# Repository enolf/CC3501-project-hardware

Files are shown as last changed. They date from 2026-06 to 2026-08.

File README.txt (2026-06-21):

KiCad Local History Directory
=============================

This directory contains automatic snapshots of your project files.
KiCad periodically saves copies of your work here, allowing you to
recover from accidental changes or data loss.

You can browse and restore previous versions through KiCad's
File > Local History menu.

To disable this feature:
  Preferences > Common > Project Backup > Enable automatic backups

This directory can be safely deleted if you no longer need the
history, but doing so will permanently remove all saved snapshots.

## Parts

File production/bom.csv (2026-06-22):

Designator | Footprint | Quantity | Value | LCSC Part #
C1 | 0402 | 1 | 22pF | C1555
C10, C11, C12, C13, C14, C15, C16, C17, C18, C20, C22, C3, C35, C36, C37, C38, C39, C40, C41, C42, C9 | 0402 | 21 | 100nF | C1525
C19, C21, C6 | 0402 | 3 | 10uF | C15525
C2 | 0603 | 1 | 10uF | C19702
C23 | 0402 | 1 | 22pF C0G ±5% | C1555
C24 | 0402 | 1 | 22pF C0G ±5% | C1555
C25, C26 | 0805 | 2 | 62p NP0 2% | C520069
C27, C28 | 0603 | 2 | 56p | C107053
C29, C30, C31, C32 | 0603 | 4 | 270p NP0 2% | C327196
C33 | 0603 | 1 | 100n X7R 10% | C14663
C34 | 0603 | 1 | 1nF X7R ±10% | C1588
C4, C5 | 0402 | 2 | 33pF | C1562
C7, C8 | 0402 | 2 | 1uF | C52923
D1 | SOT-143 | 1 | PRTR5V0U2X | C316030
G1 | piicodev_logo_14.2x3.4mm | 1 | LOGO_PiicoDev
G7 | Art_2 | 1 | Label_PCB_Art
J1 | USB_C_Receptacle_G-Switch_GT-USB-7010ASV | 1 | USB_C_Receptacle_USB2.0_16P | C2988369
J4 | PinHeader_1x03_P2.54mm_Vertical | 1 | Conn_01x03_Socket
J5 | PinHeader_1x04_P2.54mm_Vertical | 1 | Conn_01x04_Socket
J6 | PinHeader_1x08_P2.54mm_Vertical | 1 | Conn_01x08_Socket
J7 | PinHeader_1x04_P2.54mm_Vertical | 1 | Conn_01x04
J8 | PinHeader_1x06_P2.54mm_Vertical | 1 | Conn_01x06_Socket
J9 | PinHeader_1x02_P2.54mm_Vertical | 1 | Conn_01x02_Socket
L1 | IND-SMD_L4.5-W4.0 | 1 | 1uH | C2929415
L2, L3 | 0805 | 2 | 1uH | C108959
L4 | 0805 | 1 | 10uH | C1046
Q1 | SOT-23 | 1 | SS8550 | C8542
Q3, Q4 | SOT-23 | 2 | AO3401A | C15127
R1, R2 | 0201 | 2 | 5K1 | C23186
R10 | 0603 | 1 | 4.7k | C23162
R11, R14, R15, R28 | 0402 | 4 | 100 | C25076
R12, R29 | 0201 | 2 | 100k | C25803
R13 | 0201 | 1 | 27R | C25190
R16 | 0805 | 1 | 20k | C4328
R17 | 0805 | 1 | 8.2k | C17828
R18, R19, R20, R21, R22, R23, R26, R27, R5 | 0805 | 9 | 10k | C17414
R24, R6, R7 | 0402 | 3 | 1k | C11702
R25 | 0603 | 1 | 820R | C23253
R3, R4 | 0603 | 2 | 27R | C25190
R8 | 0603 | 1 | 100k | C25803
R9 | 0603 | 1 | 22.1k | C31850
SW1, SW2, SW3 | SW_Push_1P1T_XKB_TS-1187A | 3 | SW_Push | C318884
U1 | QFN-56-1EP_7x7mm_P0.4mm_EP3.2x3.2mm | 1 | RP2040 | C2040
U3 | VQFN-32-1EP_5x5mm_P0.5mm_EP3.1x3.1mm_ThermalVias | 1 | MFRC522 | C54582189
U4 | SOT95P285X130-5N | 1 | SY8089A1AAC | C479074
U7 | SOIC-16_3.9x9.9mm_P1.27mm | 1 | HX711 | C6705483
U8 | SOIC-8_L5.3-W5.3-P1.27-LS8.0-BL | 1 | W25Q128JVSIQTR | C97521
Y1 | Crystal_SMD_TXC_7M-4Pin_3.2x2.5mm | 1 | X322512MSB4SI | C9002
Y2 | Crystal_SMD_3225-4Pin_3.2x2.5mm | 1 | Crystal_GND23 | C113669

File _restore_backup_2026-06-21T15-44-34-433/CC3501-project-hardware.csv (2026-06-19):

Reference | Value | Footprint | Do Not Place | Exclude from BOM | Exclude from Board | Exclude from Simulation | LCSC PN
Y1 | 27.12MHz 12pF | Crystal:Crystal_SMD_TXC_7M-4Pin_3.2x2.5mm
Y1 | X322512MSB4SI | X322512MSB4SI |  |  |  |  | C9002
U8 | W25Q128JVSIQTR | lcsc:SOIC-8_L5.3-W5.3-P1.27-LS8.0-BL |  |  |  |  | C97521
U7 | HX711 | Package_SO:SOIC-16_3.9x9.9mm_P1.27mm |  |  |  |  | C6705483
U4 | SY8089A1AAC | SOT95P285X130-5N |  |  |  |  | C479074
U2 | DS18B20 | Package_TO_SOT_THT:TO-92_Inline
U1 | RP2040 | Package_DFN_QFN:QFN-56-1EP_7x7mm_P0.4mm_EP3.2x3.2mm |  |  |  |  | C2040
U1 | MFRC522 | Package_DFN_QFN:VQFN-32-1EP_5x5mm_P0.5mm_EP3.1x3.1mm_ThermalVias
S2 | TS-1187A-B-A-B | Button_Switch_SMD:SW_Push_1P1T_XKB_TS-1187A |  |  |  |  | C318884
S1 | TS-1187A-B-A-B | Button_Switch_SMD:SW_Push_1P1T_XKB_TS-1187A |  |  |  |  | C318884
R25 | 820R | Resistor_SMD:R_0603_1608Metric
R24 | 1k | Resistor_SMD:R_0603_1608Metric
R23 | 10k | Resistor_SMD:R_0402_1005Metric
R22 | 10k | Resistor_SMD:R_0402_1005Metric
R21 | 10k | Resistor_SMD:R_0402_1005Metric
R20 | 10k
R19 | 10k
R18 | 10k
R17 | 10k
R16 | 15k
R15 | 100
R14 | 100
R13 | 100
R12 | 0603WAF1003T5E | Imported Altium Library:FP-CRCW0603-e3-IPC_B |  |  |  |  | C25803
R11 | 100 | Resistor_SMD:R_0402_1005Metric |  |  |  |  | C25076
R10 | 4.7k | Resistor_SMD:R_0603_1608Metric |  |  |  |  | C23162
R9 | 22.1k | Resistor_SMD:R_0603_1608Metric |  |  |  |  | C31850
R8 | 100k | Resistor_SMD:R_0603_1608Metric |  |  |  |  | C25803
R7 | 1K | Resistor_SMD:R_0402_1005Metric |  |  |  |  | C11702
R6 | 1k | Resistor_SMD:R_0402_1005Metric |  |  |  |  | C11702
R5 | 10k | Resistor_SMD:R_0603_1608Metric |  |  |  |  | C25804
R4 | 27R | Resistor_SMD:R_0201_0603Metric |  |  |  |  | C25190
R3 | 27R | Resistor_SMD:R_0201_0603Metric |  |  |  |  | C25190
R2 | 5K1 | Resistor_SMD:R_0201_0603Metric |  |  |  |  | C23186
R1 | 5K1 | Resistor_SMD:R_0201_0603Metric |  |  |  |  | C23186
Q2 | S8550 | Package_TO_SOT_THT:TO-92_Inline
Q1 | AO3400A | Package_TO_SOT_SMD:SOT-23 |  |  |  |  | C20917
NT11 | Net-Tie_2 | PiicoDev RFID MFRC522:NetTie-2_SMD_Pad0.80mm
NT10 | Net-Tie_2 | PiicoDev RFID MFRC522:NetTie-2_SMD_Pad0.80mm
NT9 | Net-Tie_2_Top | PiicoDev RFID MFRC522:NetTie-2_SMD_Pad0.80mm
NT8 | Net-Tie_2_Top | PiicoDev RFID MFRC522:NetTie-2_SMD_Pad0.80mm
NT4 | Net-Tie_2 | PiicoDev RFID MFRC522:NetTie-2_SMD_Pad0.80mm
L2 | 1uH | Inductor_SMD:L_0603_1608Metric
L1 | 1.0uH | SamacSys_Parts:IND-SMD_L4.5-W4.0 |  |  |  |  | C2929415
L1 | 1uH | Inductor_SMD:L_0603_1608Metric
J7 | Conn_01x06_Socket
J6 | Conn_01x08_Socket
J4 | Conn_01x04_Socket
J3 | Conn_01x03_Socket | Connector_PinHeader_2.54mm:PinHeader_1x03_P2.54mm_Vertical
J2 | Conn_01x03_Socket | Connector_PinSocket_2.54mm:PinSocket_1x03_P2.54mm_Vertical
J1 | USB_C_Receptacle_USB2.0_16P | Connector_USB:USB_C_Receptacle_G-Switch_GT-USB-7010ASV |  |  |  |  | C2988369
J1 | Conn_01x03_Socket | Connector_PinSocket_2.54mm:PinSocket_1x03_P2.54mm_Vertical
DS1 | ILI9341 | SamacSys_Parts:ILI9341
D1 | PRTR5V0U2X | Package_TO_SOT_SMD:SOT-143 |  |  |  |  | C316030
C38 | 100n | Capacitor_SMD:C_0402_1005Metric
C37 | 100n | Capacitor_SMD:C_0402_1005Metric
C36 | 100n | Capacitor_SMD:C_0402_1005Metric
C35 | 100n | Capacitor_SMD:C_0402_1005Metric
C34 | 1n NP0 10% | Capacitor_SMD:C_0603_1608Metric
C33 | 100n X7R 10% | Capacitor_SMD:C_0402_1005Metric
C32 | 270p NP0 2% | Capacitor_SMD:C_0603_1608Metric
C31 | 270p NP0 2% | Capacitor_SMD:C_0603_1608Metric
C30 | 270p NP0 2% | Capacitor_SMD:C_0603_1608Metric
C29 | 270p NP0 2% | Capacitor_SMD:C_0603_1608Metric
C28 | 56p | Capacitor_SMD:C_0603_1608Metric
C27 | 56p | Capacitor_SMD:C_0603_1608Metric
C26 | 62p NP0 2% | Capacitor_SMD:C_0603_1608Metric
C25 | 62p NP0 2% | Capacitor_SMD:C_0603_1608Metric
C24 | 22p NP0 | Capacitor_SMD:C_0402_1005Metric
C23 | 22p NP0 | Capacitor_SMD:C_0402_1005Metric
C22 | 0.1uF
C21 | 10uF
C20 | 0.1uF
C19 | 10uF
C18 | CL05B104KO5NNNC | Imported Altium Library:CAPC1050X55X23ML05T13 |  |  |  |  | C1525
C17 | CL05B104KO5NNNC | Capacitor_SMD:C_0402_1005Metric |  |  |  |  | C1525
C16 | CL05B104KO5NNNC | Capacitor_SMD:C_0402_1005Metric |  |  |  |  | C1525
C15 | CL05B104KO5NNNC | Capacitor_SMD:C_0402_1005Metric |  |  |  |  | C1525
C14 | CL05B104KO5NNNC | Capacitor_SMD:C_0402_1005Metric |  |  |  |  | C1525
C13 | CL05B104KO5NNNC | Capacitor_SMD:C_0402_1005Metric |  |  |  |  | C1525
C12 | CL05B104KO5NNNC | Capacitor_SMD:C_0402_1005Metric |  |  |  |  | C1525
C11 | CL05B104KO5NNNC | Capacitor_SMD:C_0402_1005Metric |  |  |  |  | C1525
C10 | CL05B104KO5NNNC | Capacitor_SMD:C_0402_1005Metric |  |  |  |  | C1525
C9 | CL05B104KO5NNNC | Capacitor_SMD:C_0402_1005Metric |  |  |  |  | C1525
C8 | 1uF | Capacitor_SMD:C_0402_1005Metric |  |  |  |  | C52923
C7 | 1uF | Capacitor_SMD:C_0402_1005Metric |  |  |  |  | C52923
C6 | 10uF | Capacitor_SMD:C_0402_1005Metric |  |  |  |  | C15525
C5 | 33pF | Capacitor_SMD:C_0402_1005Metric |  |  |  |  | C1562
C4 | 33pF | Capacitor_SMD:C_0402_1005Metric |  |  |  |  | C1562
C3 | 100nF | Capacitor_SMD:C_0402_1005Metric |  |  |  |  | C1525
C2 | 10uF | Capacitor_SMD:C_0603_1608Metric |  |  |  |  | C19702
C1 | 22pF | Capacitor_SMD:C_0402_1005Metric |  |  |  |  | C1555

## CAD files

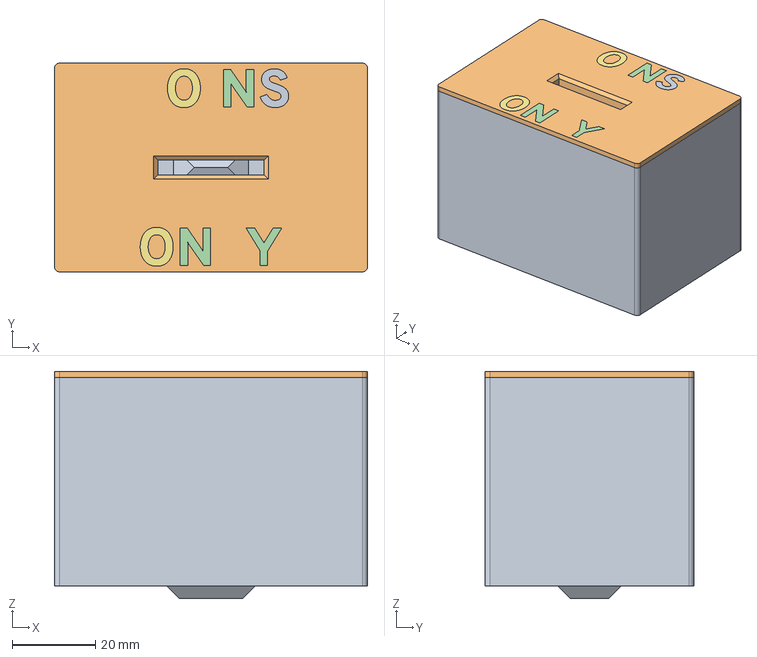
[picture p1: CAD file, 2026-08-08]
3D Printed Enclosure/Money Box.step
75.0 x 50.0 x 54.5 mm

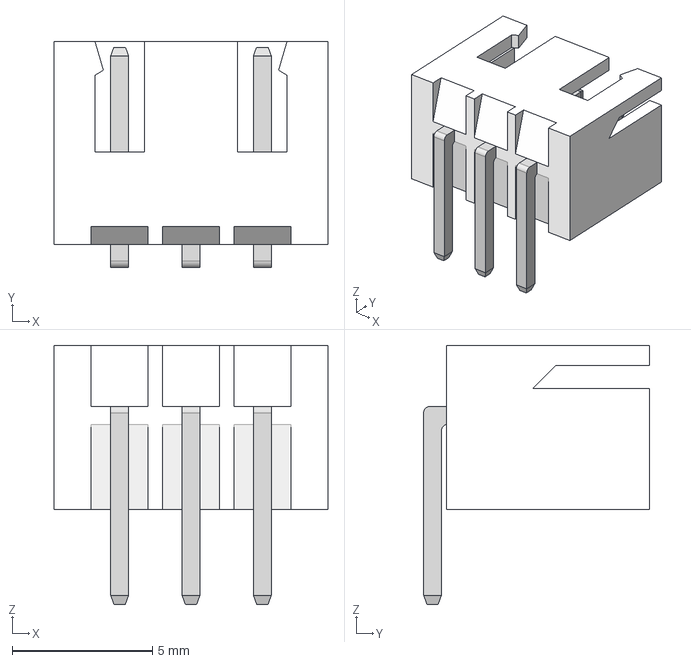
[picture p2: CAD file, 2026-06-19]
_restore_backup_2026-06-21T14-04-23-622/DS18B20_breakout_board/DS18B20-Breakout-Board/3D Files/JST - XH - Thru (R) - 3Pin - 2.54mm.stp
9.75 x 8.04 x 9.22 mm

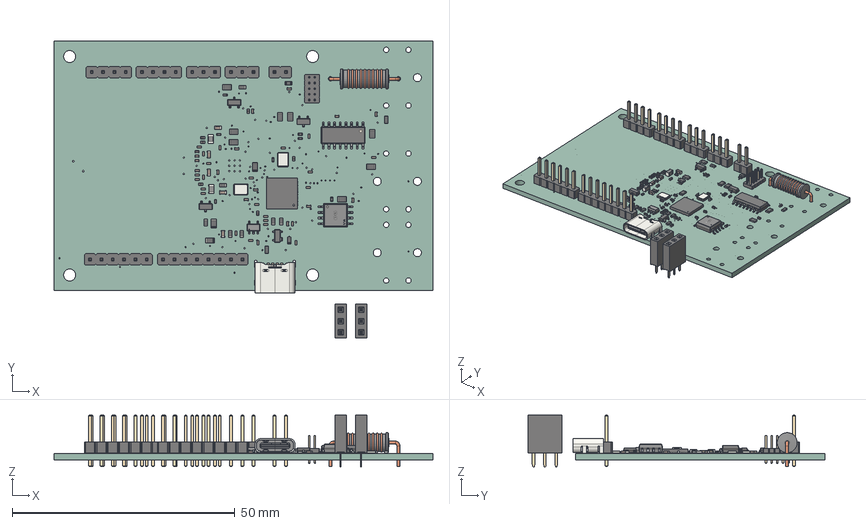
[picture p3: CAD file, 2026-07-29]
PCB.step
85.0 x 66.6 x 11.6 mm
C_0402_1005Metric x 45
R_0603_1608Metric x 11
SOT-23 x 3
R_0402_1005Metric x 7
R_0805_2012Metric x 11
Crystal_SMD_3225-4Pin_3.2x2.5mm
C_0603_1608Metric x 5
PinSocket_1x03_P2.54mm_Vertical x 2
QFN-56-1EP_7x7mm_P0.4mm_EP3.2x3.2mm
SOIC-16_3.9x9.9mm_P1.27mm
L_0805_2012Metric x 2
SOT-143
PinHeader_1x03_P2.54mm_Vertical x 2
PinHeader_1x06_P2.54mm_Vertical
PinHeader_2x05_P1.27mm_Vertical
PinHeader_1x04_P2.54mm_Vertical x 2
PinHeader_1x02_P2.54mm_Vertical
PinsArrayL
PinsArrayR
L_Axial_L11.0mm_D4.5mm_P15.24mm_Horizontal_Fastron_MECC
PinHeader_1x08_P2.54mm_Vertical
Crystal_SMD_TXC_7M-4Pin_3.2x2.5mm
USB_C_Receptacle_GCT_USB4125-xx-x_6P_TopMnt_Horizontal
SOIC-8_L5.3-W5.3-H1.9-LS7.9-P1.27
CC3501-project-hardware_PCB

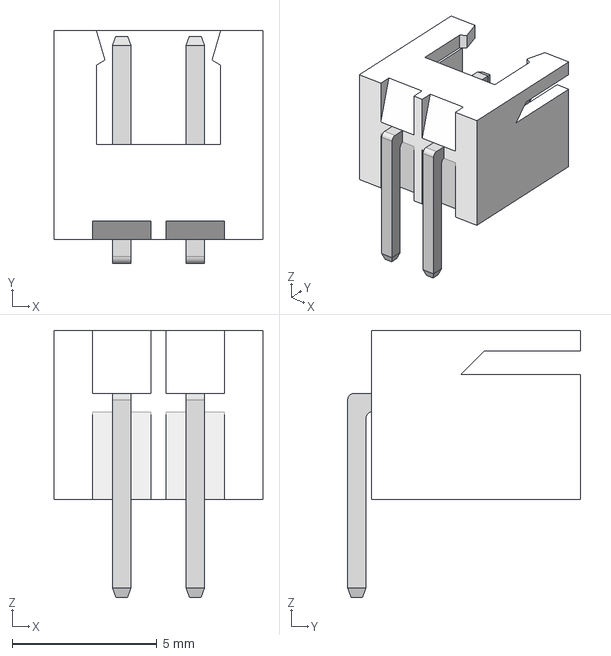
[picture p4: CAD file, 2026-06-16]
_restore_backup_2026-06-21T14-04-23-622/DS18B20_breakout_board/DS18B20-Breakout-Board/3D Files/JST - XH - Thru (R) - 2Pin - 2.54mm.stp
7.21 x 8.04 x 9.22 mm

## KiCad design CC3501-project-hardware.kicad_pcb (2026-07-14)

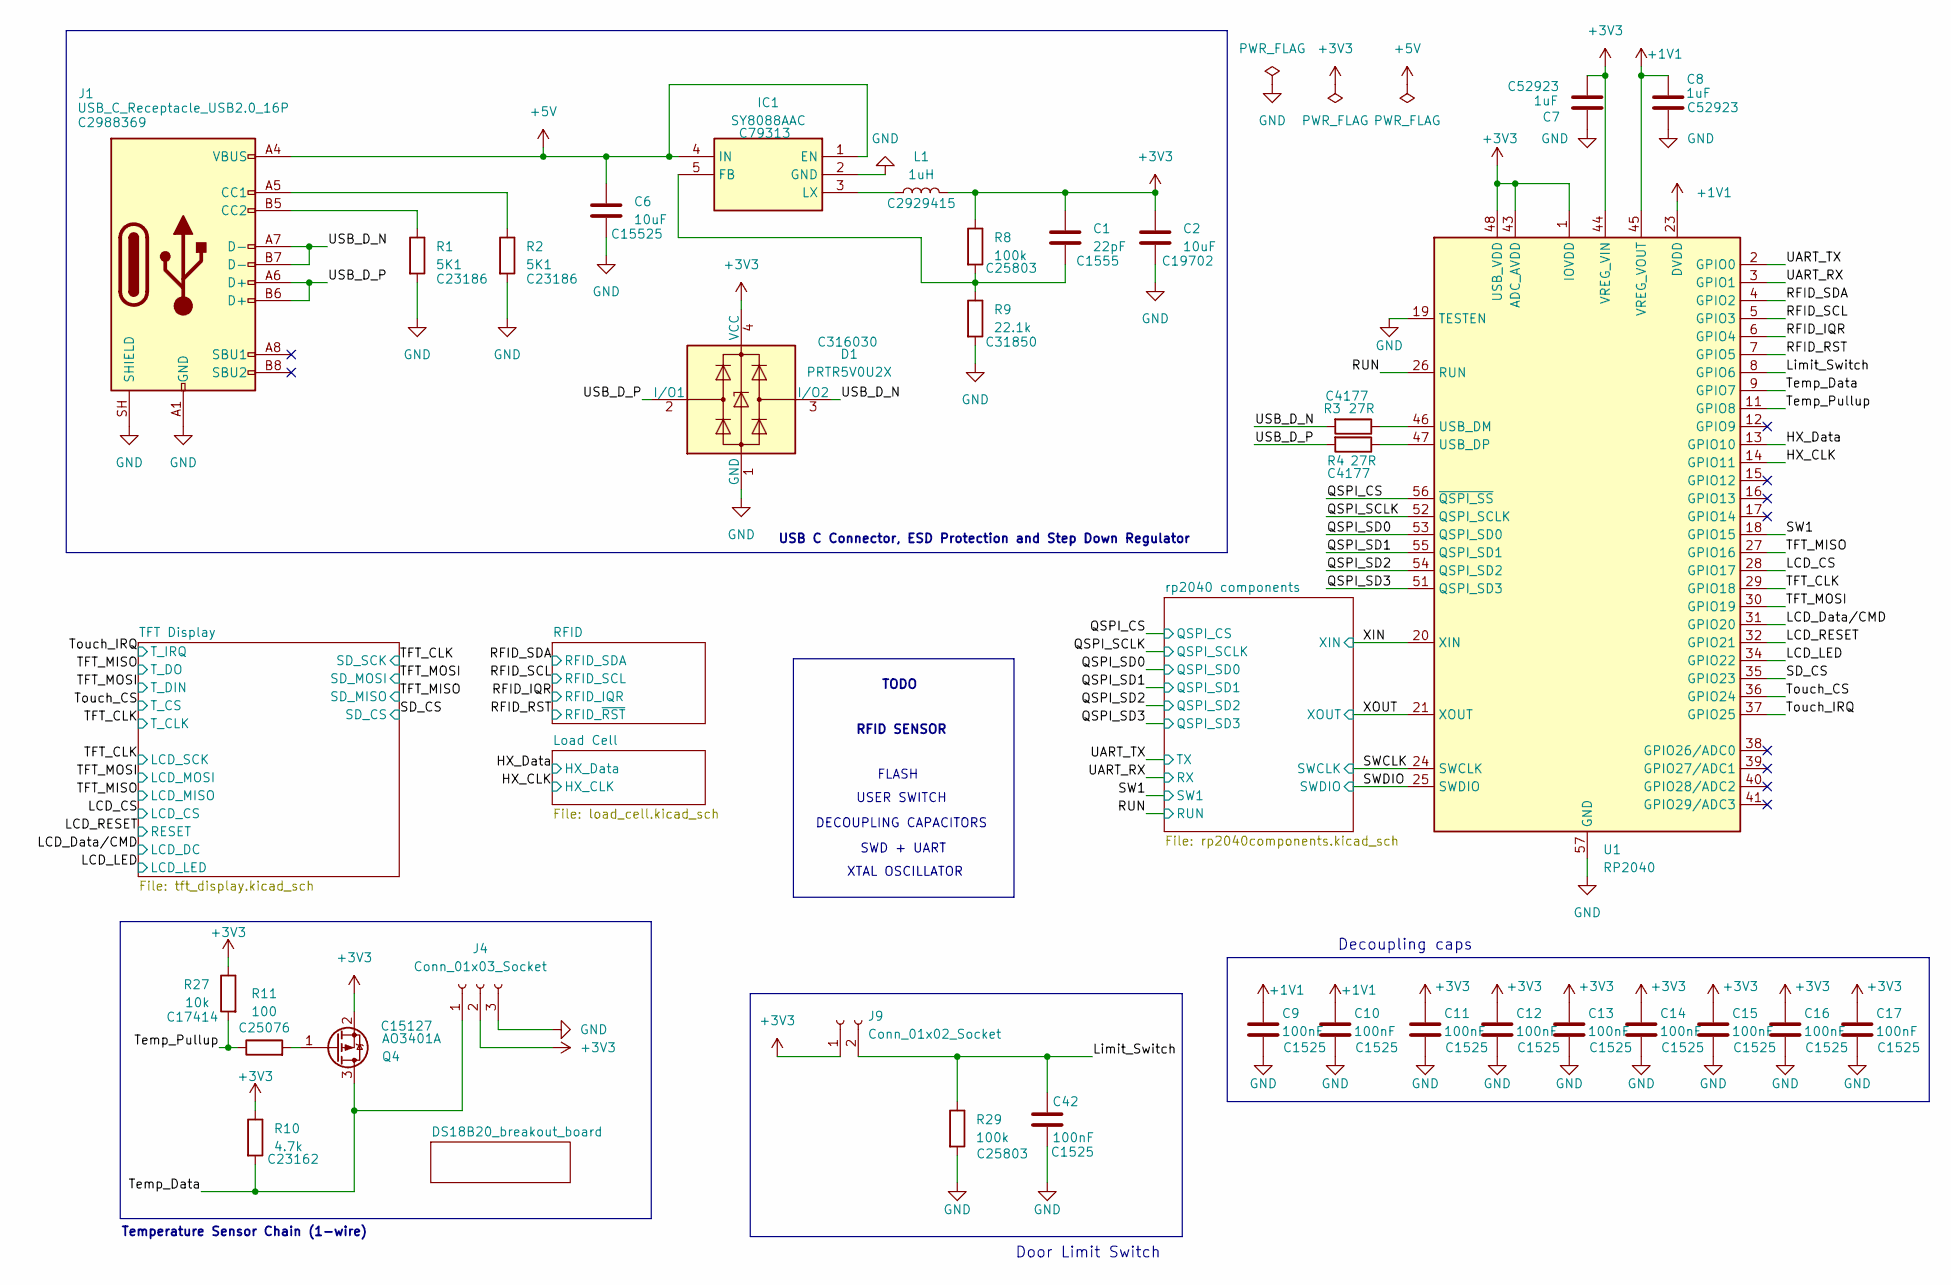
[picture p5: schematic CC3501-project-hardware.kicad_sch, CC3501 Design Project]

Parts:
C1: 22pF; C_0402_1005Metric; LCSC PN C1555
C2: 10uF; C_0603_1608Metric; LCSC PN C19702
C6: 10uF; C_0402_1005Metric; LCSC PN C15525
C7, C8: 1uF; C_0402_1005Metric; LCSC PN C52923
C9, C10, C11, C12, C13, C14, C15, C16, C17, C42: 100nF; C_0402_1005Metric; LCSC PN C1525
D1: PRTR5V0U2X; SOT-143; LCSC PN C316030
IC1: SY8088AAC; SOT95P285X140-5N; Manufacturer_Part_Number SY8088AAC
J1: USB_C_Receptacle_USB2.0_16P; USB_C_Receptacle_G-Switch_GT-USB-7010ASV; LCSC PN C2988369
J4: Conn_01x03_Socket; PinHeader_1x03_P2.54mm_Vertical
J9: Conn_01x02_Socket; PinHeader_1x02_P2.54mm_Vertical
L1: 1uH; IND-SMD_L4.5-W4.0; LCSC PN C2929415
Q4: AO3401A; SOT-23; LCSC PN C15127
R1, R2: 5K1; R_0603_1608Metric; LCSC PN C23186
R3, R4: 27R; R_0603_1608Metric; LCSC PN C4177
R8, R29: 100k; R_0603_1608Metric; LCSC PN C25803
R9: 22.1k; R_0603_1608Metric; LCSC PN C31850
R10: 4.7k; R_0603_1608Metric; LCSC PN C23162
R11: 100; R_0402_1005Metric; LCSC PN C25076
R27: 10k; R_0805_2012Metric; LCSC PN C17414
U1: RP2040; QFN-56-1EP_7x7mm_P0.4mm_EP3.2x3.2mm; LCSC PN C2040

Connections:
+1V1: C8.2, C9.1, C10.1, U1.23 (DVDD), U1.45 (VREG_VOUT), U1.50 (DVDD)
+5V: C6.1, IC1.1 (EN), IC1.4 (IN), J1.A4 (VBUS), J1.A9 (VBUS), J1.B4 (VBUS), J1.B9 (VBUS); also elsewhere on the board
/HX_CLK: U1.14 (GPIO11); also elsewhere on the board
/HX_Data: U1.13 (GPIO10); also elsewhere on the board
/LCD_CS: U1.28 (GPIO17); also elsewhere on the board
/LCD_Data/CMD: U1.31 (GPIO20); also elsewhere on the board
/LCD_LED: U1.34 (GPIO22); also elsewhere on the board
/LCD_RESET: U1.32 (GPIO21); also elsewhere on the board
/Limit_Switch: C42.1, J9.2, R29.1, U1.8 (GPIO6)
/QSPI_CS: U1.56 (~QSPI_SS); also elsewhere on the board
/QSPI_SCLK: U1.52 (QSPI_SCLK); also elsewhere on the board
/QSPI_SD0: U1.53 (QSPI_SD0); also elsewhere on the board
/QSPI_SD1: U1.55 (QSPI_SD1); also elsewhere on the board
/QSPI_SD2: U1.54 (QSPI_SD2); also elsewhere on the board
/QSPI_SD3: U1.51 (QSPI_SD3); also elsewhere on the board
/RFID_IQR: U1.6 (GPIO4); also elsewhere on the board
/RFID_RST: U1.7 (GPIO5); also elsewhere on the board
/RFID_SCL: U1.5 (GPIO3); also elsewhere on the board
/RFID_SDA: U1.4 (GPIO2); also elsewhere on the board
/RUN: U1.26 (RUN); also elsewhere on the board
/SD_CS: U1.35 (GPIO23); also elsewhere on the board
/SW1: U1.18 (GPIO15); also elsewhere on the board
/SWCLK: U1.24 (SWCLK); also elsewhere on the board
/SWDIO: U1.25 (SWDIO); also elsewhere on the board
/TFT_CLK: U1.29 (GPIO18); also elsewhere on the board
/TFT_MISO: U1.27 (GPIO16); also elsewhere on the board
/TFT_MOSI: U1.30 (GPIO19); also elsewhere on the board
/Temp_Data: J4.1, Q4.3 (D), R10.2, U1.9 (GPIO7)
/Temp_Pullup: R11.1, R27.2, U1.11 (GPIO8)
/Touch_CS: U1.36 (GPIO24); also elsewhere on the board
/Touch_IRQ: U1.37 (GPIO25); also elsewhere on the board
/USB_D_N: D1.3 (I/O2), J1.A7 (D-), J1.B7 (D-), R3.2
/USB_D_P: D1.2 (I/O1), J1.A6 (D+), J1.B6 (D+), R4.2
/XIN: U1.20 (XIN); also elsewhere on the board
/XOUT: U1.21 (XOUT); also elsewhere on the board
GND: C2.2, C6.2, C7.1, C8.1, C9.2, C10.2, C11.2, C12.2, C13.2, C14.2, C15.2, C16.2, C17.2, C42.2, D1.1 (GND), IC1.2 (GND), J1.A1 (GND), J1.A12 (GND), J1.B1 (GND), J1.B12 (GND), J1.SH (SHIELD), J4.3, R1.2, R2.2, R9.2, R29.2, U1.19 (TESTEN), U1.57 (GND); also elsewhere on the board
unnamed: C1.2, IC1.5 (FB), R8.2, R9.1
unnamed: IC1.3 (LX), L1.2
unnamed: J1.A5 (CC1), R2.1
unnamed: J1.B5 (CC2), R1.1
unnamed: Q4.1 (G), R11.2
unnamed: R3.1, U1.46 (USB_DM)
unnamed: R4.1, U1.47 (USB_DP)

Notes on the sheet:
TODO
FLASH
DECOUPLING CAPACITORS
Door Limit Switch
Decoupling caps
RFID SENSOR
SWD + UART
XTAL OSCILLATOR
USB C Connector, ESD Protection and Step Down Regulator
USER SWITCH
Temperature Sensor Chain (1-wire)

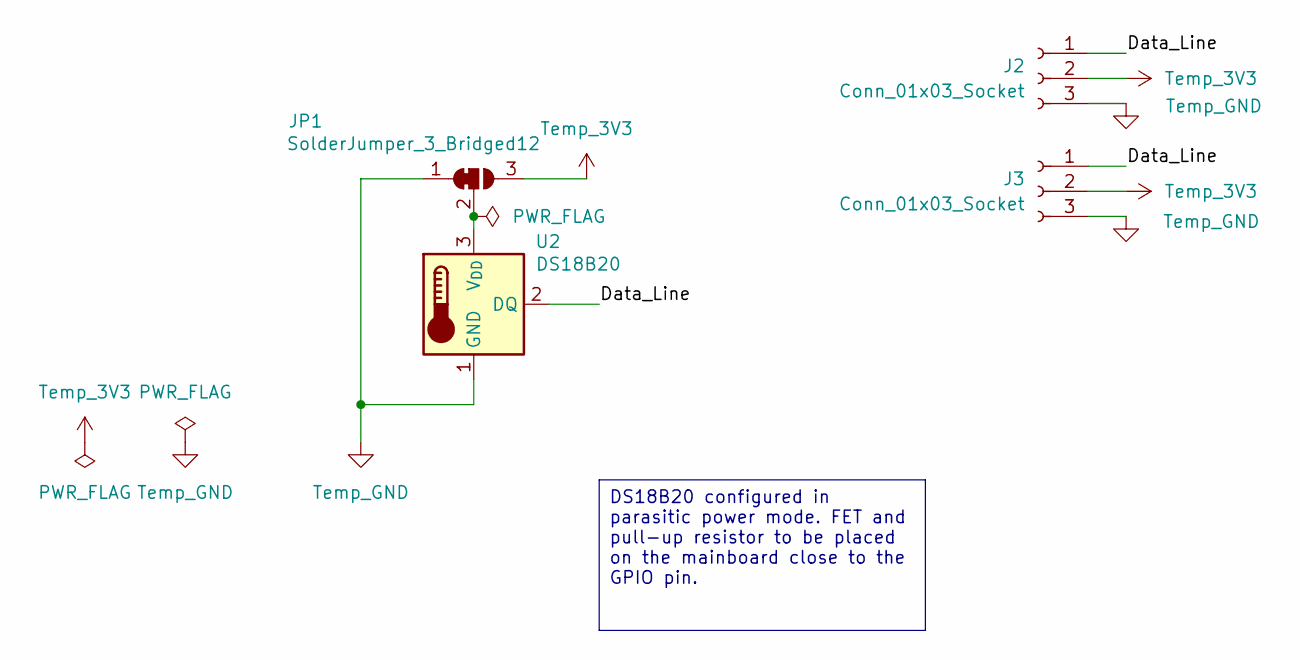
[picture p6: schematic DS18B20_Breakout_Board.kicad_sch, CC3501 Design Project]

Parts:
J2, J3: Conn_01x03_Socket; PinSocket_1x03_P2.54mm_Vertical
JP1: SolderJumper_3_Bridged12; SolderJumper-3_P1.3mm_Bridged12_RoundedPad1.0x1.5mm_NumberL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
U2: DS18B20; TO-92_Inline

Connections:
Temp_3V3: J2.2, J3.2, JP1.3 (B)

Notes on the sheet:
DS18B20 configured in parasitic power mode. FET and pull-up resistor to be placed on the mainboard close to the GPIO pin.

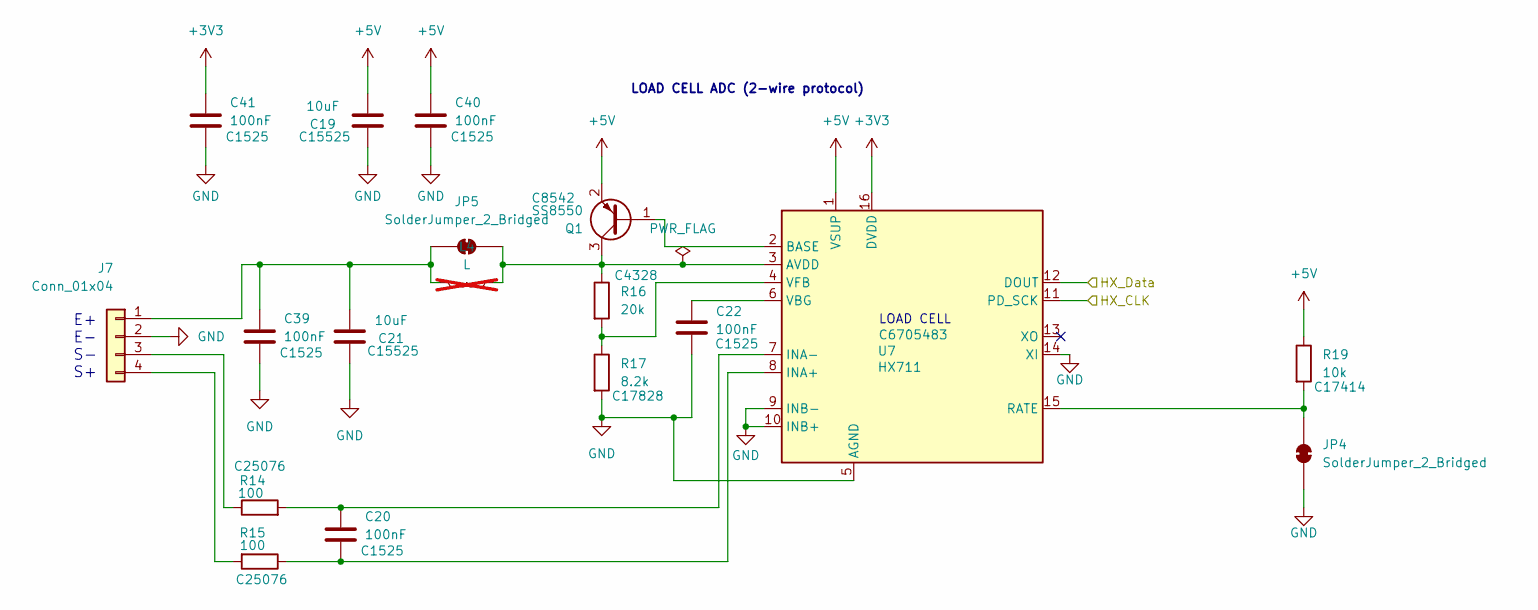
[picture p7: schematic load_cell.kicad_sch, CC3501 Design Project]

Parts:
C19, C21: 10uF; C_0402_1005Metric; LCSC PN C15525
C20, C22, C39, C40, C41: 100nF; C_0402_1005Metric; LCSC PN C1525
J7: Conn_01x04; PinHeader_1x04_P2.54mm_Vertical
JP4, JP5: SolderJumper_2_Bridged; SolderJumper-2_P1.3mm_Bridged2Bar_RoundedPad1.0x1.5mm
L4: L; L_Axial_L11.0mm_D4.5mm_P15.24mm_Horizontal_Fastron_MECC; not fitted
Q1: SS8550; SOT-23; LCSC PN C8542
R14, R15: 100; R_0402_1005Metric; LCSC PN C25076
R16: 20k; R_0805_2012Metric; LCSC PN C4328
R17: 8.2k; R_0805_2012Metric; LCSC PN C17828
R19: 10k; R_0805_2012Metric; LCSC PN C17414
U7: HX711; SOIC-16_3.9x9.9mm_P1.27mm; LCSC PN C6705483

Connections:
+5V: C19.2, C40.1, Q1.2 (E), R19.1, U7.1 (VSUP); also elsewhere on the board
/HX_CLK: U7.11 (PD_SCK); also elsewhere on the board
/HX_Data: U7.12 (DOUT); also elsewhere on the board
GND: C19.1, C21.1, C22.2, C39.2, C40.2, C41.2, J7.2, JP4.1 (A), R17.2, U7.5 (AGND), U7.9 (INB-), U7.10 (INB+), U7.14 (XI); also elsewhere on the board
unnamed: C21.2, C39.1, J7.1, JP5.2 (B), L4.1
unnamed: J7.3, R14.1
unnamed: J7.4, R15.2
unnamed: JP4.2 (B), R19.2, U7.15 (RATE)
unnamed: JP5.1 (A), L4.2, Q1.3 (C), R16.1, U7.3 (AVDD)
unnamed: Q1.1 (B), U7.2 (BASE)
unnamed: C20.2, R15.1, U7.8 (INA+)
unnamed: C20.1, R14.2, U7.7 (INA-)
unnamed: C22.1, U7.6 (VBG)
unnamed: R16.2, R17.1, U7.4 (VFB)

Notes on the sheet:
E+ E- S- S+
LOAD CELL ADC (2-wire protocol)
LOAD CELL

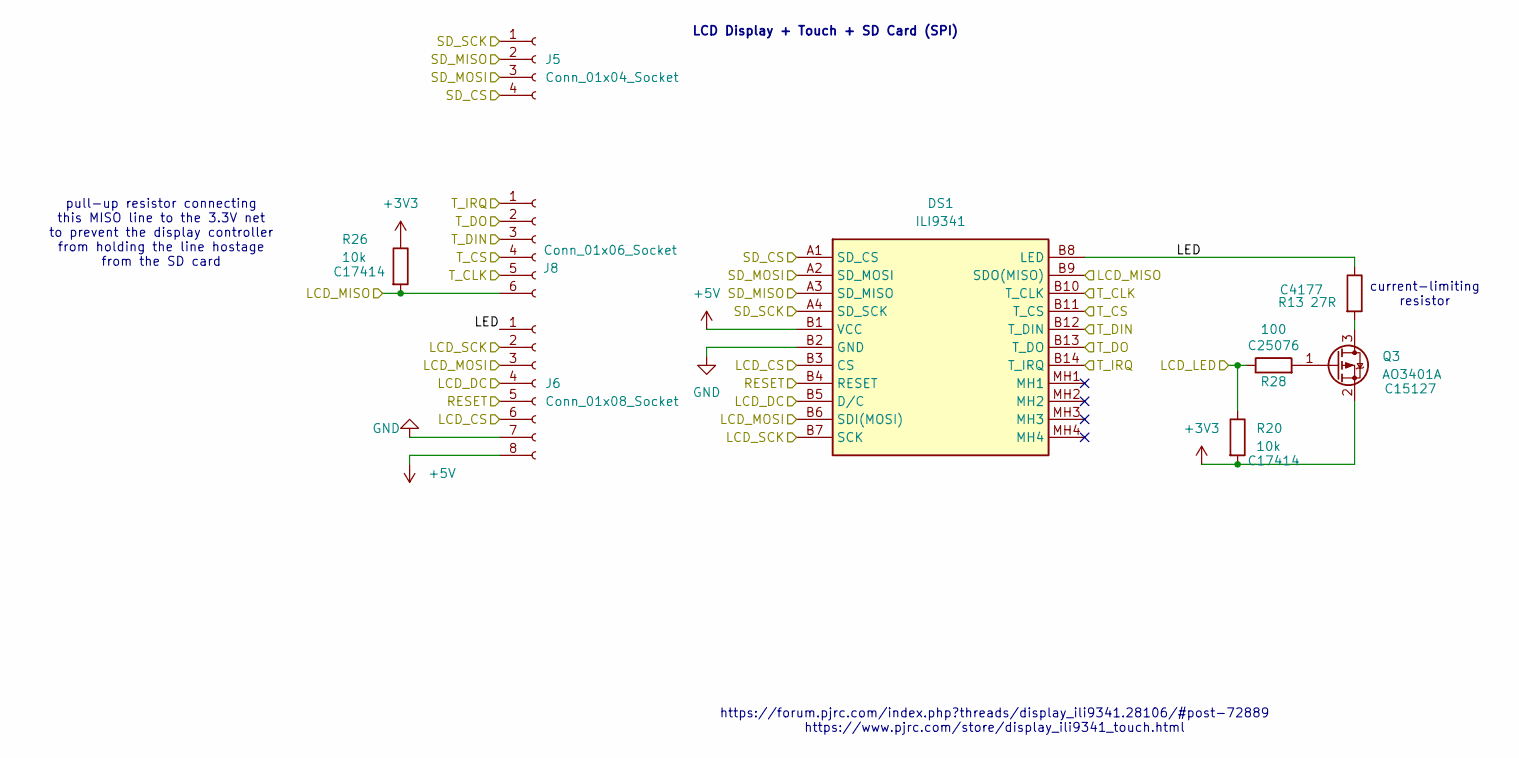
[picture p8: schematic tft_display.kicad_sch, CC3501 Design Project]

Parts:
DS1: ILI9341; Manufacturer_Part_Number ILI9341
J5: Conn_01x04_Socket; PinHeader_1x04_P2.54mm_Vertical
J6: Conn_01x08_Socket; PinHeader_1x08_P2.54mm_Vertical
J8: Conn_01x06_Socket; PinHeader_1x06_P2.54mm_Vertical
Q3: AO3401A; SOT-23; LCSC PN C15127
R13: 27R; R_0603_1608Metric; LCSC PN C4177
R20, R26: 10k; R_0805_2012Metric; LCSC PN C17414
R28: 100; R_0402_1005Metric; LCSC PN C25076

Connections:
+5V: DS1.B1 (VCC), J6.8; also elsewhere on the board
/LCD_CS: DS1.B3 (CS), J6.6; also elsewhere on the board
/LCD_Data/CMD: DS1.B5 (D/C), J6.4; also elsewhere on the board
/LCD_LED: R20.1, R28.1; also elsewhere on the board
/LCD_RESET: DS1.B4 (RESET), J6.5; also elsewhere on the board
/SD_CS: DS1.A1 (SD_CS), J5.4; also elsewhere on the board
/TFT Display/LED: DS1.B8 (LED), J6.1, R13.1
/TFT_CLK: DS1.A4 (SD_SCK), DS1.B7 (SCK), DS1.B10 (T_CLK), J5.1, J6.2, J8.5; also elsewhere on the board
/TFT_MISO: DS1.A3 (SD_MISO), DS1.B9 (SDO(MISO)), DS1.B13 (T_DO), J5.2, J8.2, J8.6, R26.2; also elsewhere on the board
/TFT_MOSI: DS1.A2 (SD_MOSI), DS1.B6 (SDI(MOSI)), DS1.B12 (T_DIN), J5.3, J6.3, J8.3; also elsewhere on the board
/Touch_CS: DS1.B11 (T_CS), J8.4; also elsewhere on the board
/Touch_IRQ: DS1.B14 (T_IRQ), J8.1; also elsewhere on the board
GND: DS1.B2 (GND), J6.7; also elsewhere on the board
unnamed: Q3.3 (D), R13.2
unnamed: Q3.1 (G), R28.2

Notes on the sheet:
LCD Display + Touch + SD Card (SPI)
https://forum.pjrc.com/index.php?threads/display_ili9341.28106/#post-72889 https://www.pjrc.com/store/display_ili9341_touch.html
current-limiting resistor
pull-up resistor connecting this MISO line to the 3.3V net to prevent the display controller from holding the line hostage from the SD card

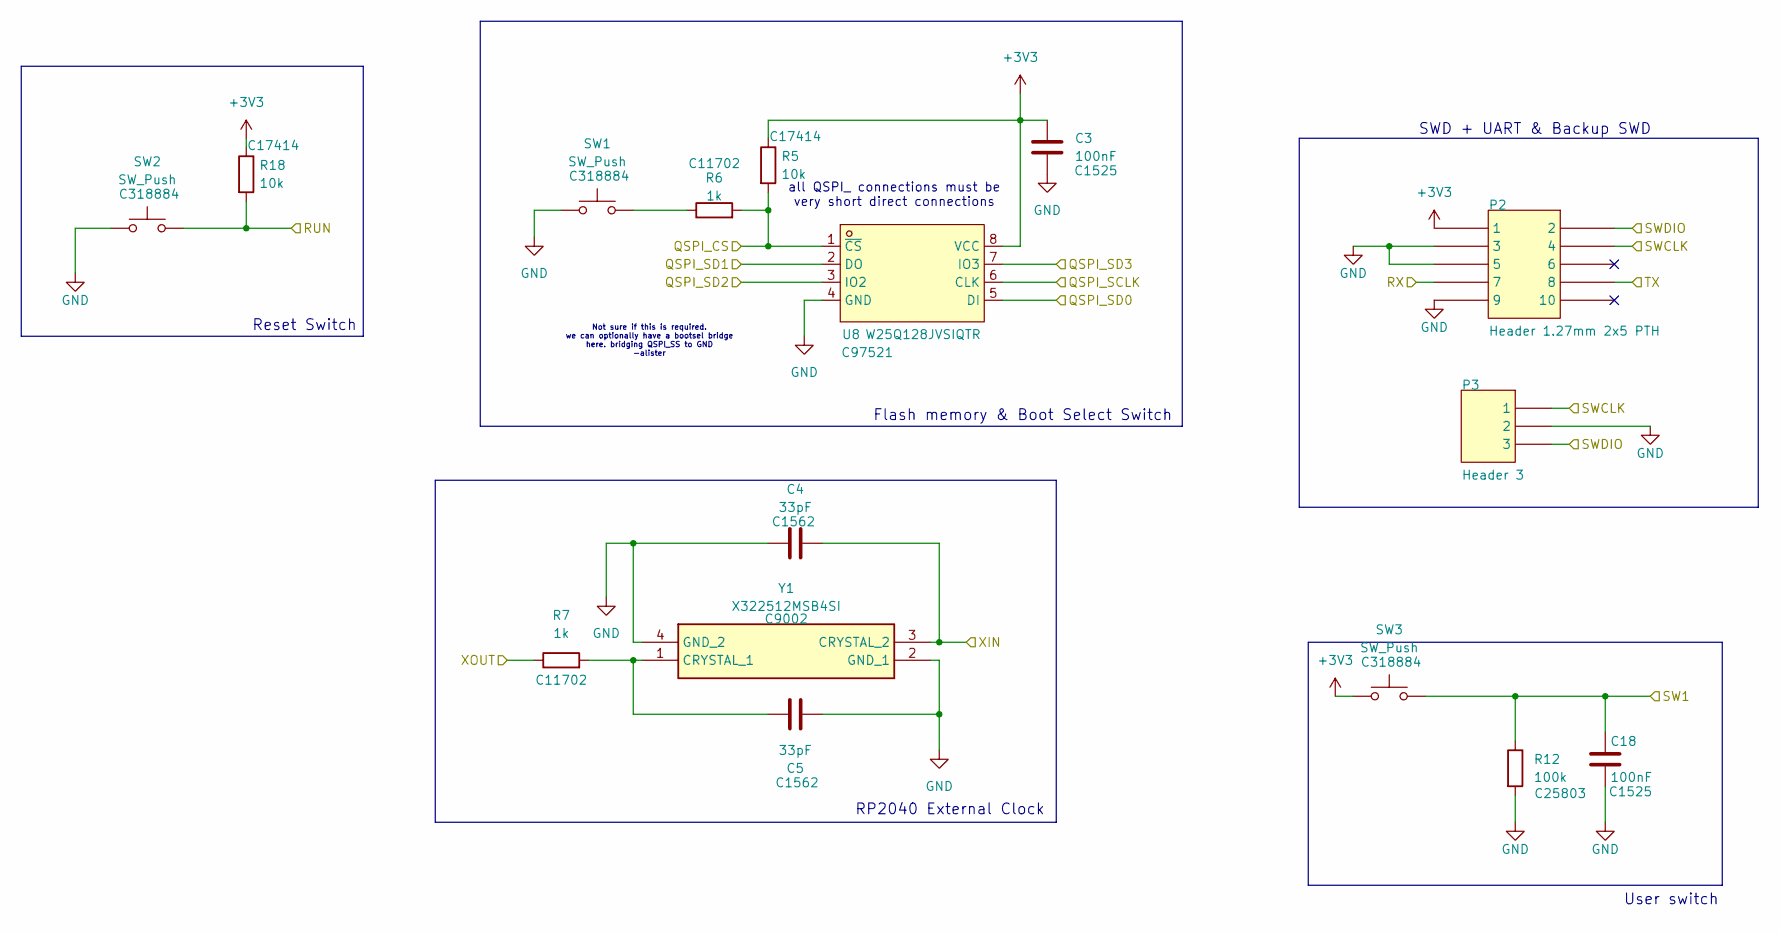
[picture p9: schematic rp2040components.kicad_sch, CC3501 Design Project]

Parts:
C3, C18: 100nF; C_0402_1005Metric; LCSC PN C1525
C4, C5: 33pF; C_0402_1005Metric; LCSC PN C1562
P2: Header 1.27mm 2x5 PTH; PinHeader_2x05_P1.27mm_Vertical
P3: Header 3; PinHeader_1x03_P2.54mm_Vertical
R5, R18: 10k; R_0805_2012Metric; LCSC PN C17414
R6, R7: 1k; R_0402_1005Metric; LCSC PN C11702
R12: 100k; R_0603_1608Metric; LCSC PN C25803
SW1, SW2, SW3: SW_Push; SW_SPST_Omron_B3F-40xx; LCSC PN C318884
U8: W25Q128JVSIQTR; SOIC-8_L5.3-W5.3-P1.27-LS8.0-BL; MPN W25Q128JVSIQ; LCSC PN C97521
Y1: X322512MSB4SI; Crystal_SMD_TXC_7M-4Pin_3.2x2.5mm; Manufacturer_Part_Number X322512MSB4SI; LCSC PN C9002

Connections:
/QSPI_CS: R5.2, R6.2, U8.1 (~CS); also elsewhere on the board
/QSPI_SCLK: U8.6 (CLK); also elsewhere on the board
/QSPI_SD0: U8.5 (DI); also elsewhere on the board
/QSPI_SD1: U8.2 (DO); also elsewhere on the board
/QSPI_SD2: U8.3 (IO2); also elsewhere on the board
/QSPI_SD3: U8.7 (IO3); also elsewhere on the board
/RUN: R18.2, SW2.2; also elsewhere on the board
/SW1: C18.1, R12.1, SW3.2; also elsewhere on the board
/SWCLK: P2.4, P3.1; also elsewhere on the board
/SWDIO: P2.2, P3.3; also elsewhere on the board
/XIN: C4.1, Y1.3 (CRYSTAL_2); also elsewhere on the board
/XOUT: R7.1; also elsewhere on the board
GND: C3.2, C4.2, C5.2, C18.2, P2.3, P2.5, P2.9, P3.2, R12.2, SW1.1, SW2.1, U8.4 (GND), Y1.2 (GND_1), Y1.4 (GND_2); also elsewhere on the board
unnamed: R6.1, SW1.2
unnamed: C5.1, R7.2, Y1.1 (CRYSTAL_1)

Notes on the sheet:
Flash memory & Boot Select Switch
RP2040 External Clock
Reset Switch
SWD + UART & Backup SWD
Not sure if this is required. we can optionally have a bootsel bridge here. bridging QSPI_SS to GND -alister
User switch
all QSPI_ connections must be very short direct connections

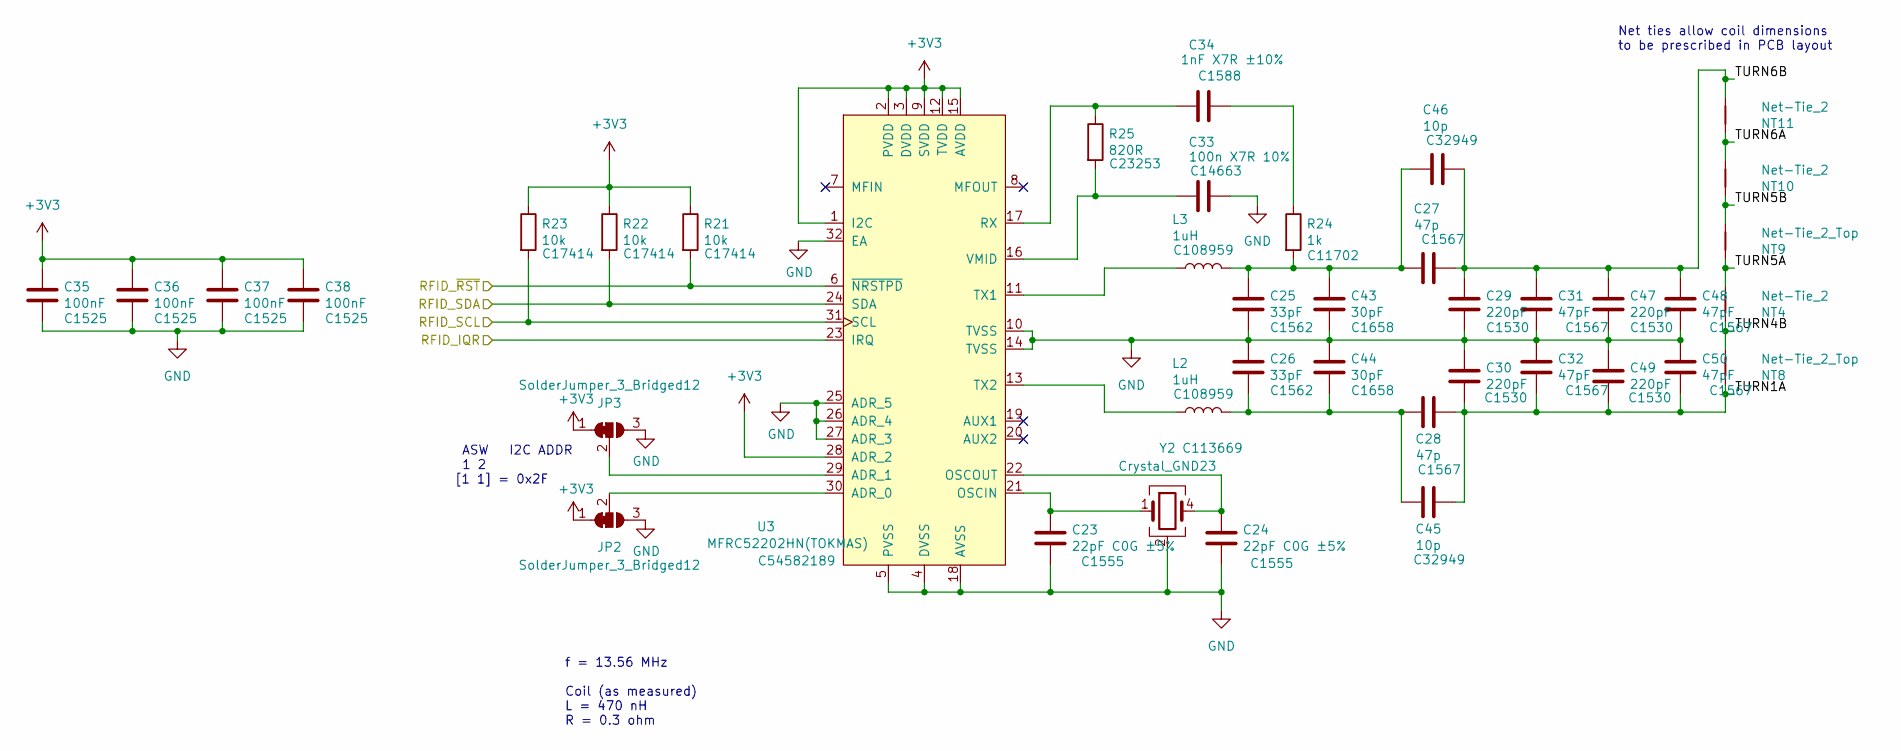
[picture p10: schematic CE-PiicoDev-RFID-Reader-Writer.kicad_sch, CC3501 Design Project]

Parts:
C23, C24: 22pF C0G ±5%; C_0402_1005Metric; LCSC PN C1555
C25, C26: 33pF; C_0402_1005Metric; LCSC PN C1562
C27, C28: 47p; C_0402_1005Metric; LCSC PN C1567
C29, C30, C47, C49: 220pF; C_0402_1005Metric; LCSC PN C1530
C31, C32, C48, C50: 47pF; C_0402_1005Metric; LCSC PN C1567
C33: 100n X7R 10%; C_0603_1608Metric; LCSC PN C14663
C34: 1nF X7R ±10%; C_0603_1608Metric; LCSC PN C1588
C35, C36, C37, C38: 100nF; C_0402_1005Metric; LCSC PN C1525
C43, C44: 30pF; C_0603_1608Metric; LCSC PN C1658
C45, C46: 10p; C_0402_1005Metric; LCSC PN C32949
JP2, JP3: SolderJumper_3_Bridged12; SolderJumper-3_P1.3mm_Bridged12_RoundedPad1.0x1.5mm_NumberL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
L2, L3: 1uH; L_0805_2012Metric; LCSC PN C108959
NT4, NT10, NT11: Net-Tie_2; NetTie-2_SMD_Pad0.80mm
NT8, NT9: Net-Tie_2_Top; NetTie-2_SMD_Pad0.80mm
R21, R22, R23: 10k; R_0805_2012Metric; LCSC PN C17414
R24: 1k; R_0402_1005Metric; LCSC PN C11702
R25: 820R; R_0603_1608Metric; LCSC PN C23253
U3: MFRC52202HN(TOKMAS); VQFN-32-1EP_5x5mm_P0.5mm_EP3.1x3.1mm_ThermalVias; LCSC PN C54582189
Y2: Crystal_GND23; Crystal_SMD_3225-4Pin_3.2x2.5mm; LCSC PN C113669

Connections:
/RFID/TURN1A: C28.1, C30.2, C32.2, C45.1, C49.2, C50.2, NT8.1
/RFID/TURN6B: C27.1, C29.1, C31.1, C46.1, C47.1, C48.1, NT11.2
/RFID_IQR: U3.23 (IRQ); also elsewhere on the board
/RFID_RST: R21.2, U3.6 (~NRSTPD); also elsewhere on the board
/RFID_SCL: R23.2, U3.31 (SCL); also elsewhere on the board
/RFID_SDA: R22.2, U3.24 (SDA); also elsewhere on the board
/TURN4B: NT4.1, NT8.2
/TURN5A: NT4.2, NT9.1
/TURN5B: NT9.2, NT10.1
/TURN6A: NT10.2, NT11.1
GND: C23.2, C24.2, C25.2, C26.1, C29.2, C30.1, C31.2, C32.1, C33.1, C35.2, C36.2, C37.2, C38.2, C43.2, C44.1, C47.2, C48.2, C49.1, C50.1, JP2.3 (B), JP3.3 (B), U3.4 (DVSS), U3.5 (PVSS), U3.10 (TVSS), U3.14 (TVSS), U3.18 (AVSS), U3.25 (ADR_5), U3.26 (ADR_4), U3.27 (ADR_3), U3.32 (EA), Y2.2 (G), Y2.3 (G); also elsewhere on the board
unnamed: C25.1, C27.2, C43.1, C46.2, L3.2, R24.2
unnamed: C26.2, C28.2, C44.2, C45.2, L2.2
unnamed: C34.1, R24.1
unnamed: JP2.2 (C), U3.30 (ADR_0)
unnamed: JP3.2 (C), U3.29 (ADR_1)
unnamed: C23.1, U3.21 (OSCIN), Y2.1
unnamed: C24.1, U3.22 (OSCOUT), Y2.4
unnamed: C34.2, R25.1, U3.17 (RX)
unnamed: L3.1, U3.11 (TX1)
unnamed: L2.1, U3.13 (TX2)
unnamed: C33.2, R25.2, U3.16 (VMID)

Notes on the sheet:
ASW I2C ADDR 1 2 [1 1] = 0x2F
f = 13.56 MHz Coil (as measured) L = 470 nH R = 0.3 ohm
Net ties allow coil dimensions to be prescribed in PCB layout

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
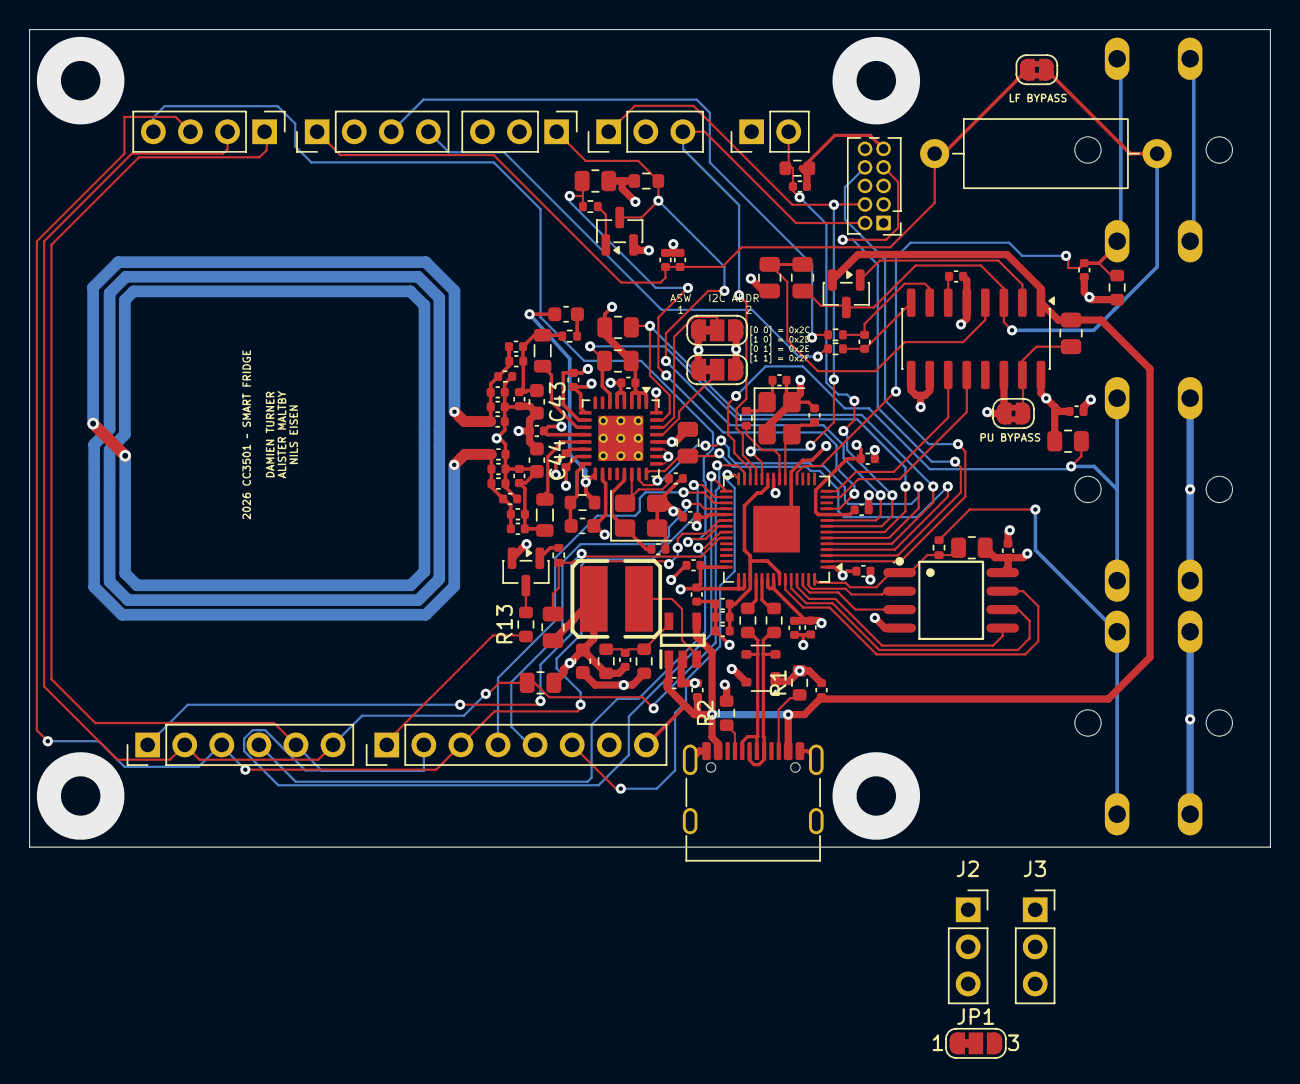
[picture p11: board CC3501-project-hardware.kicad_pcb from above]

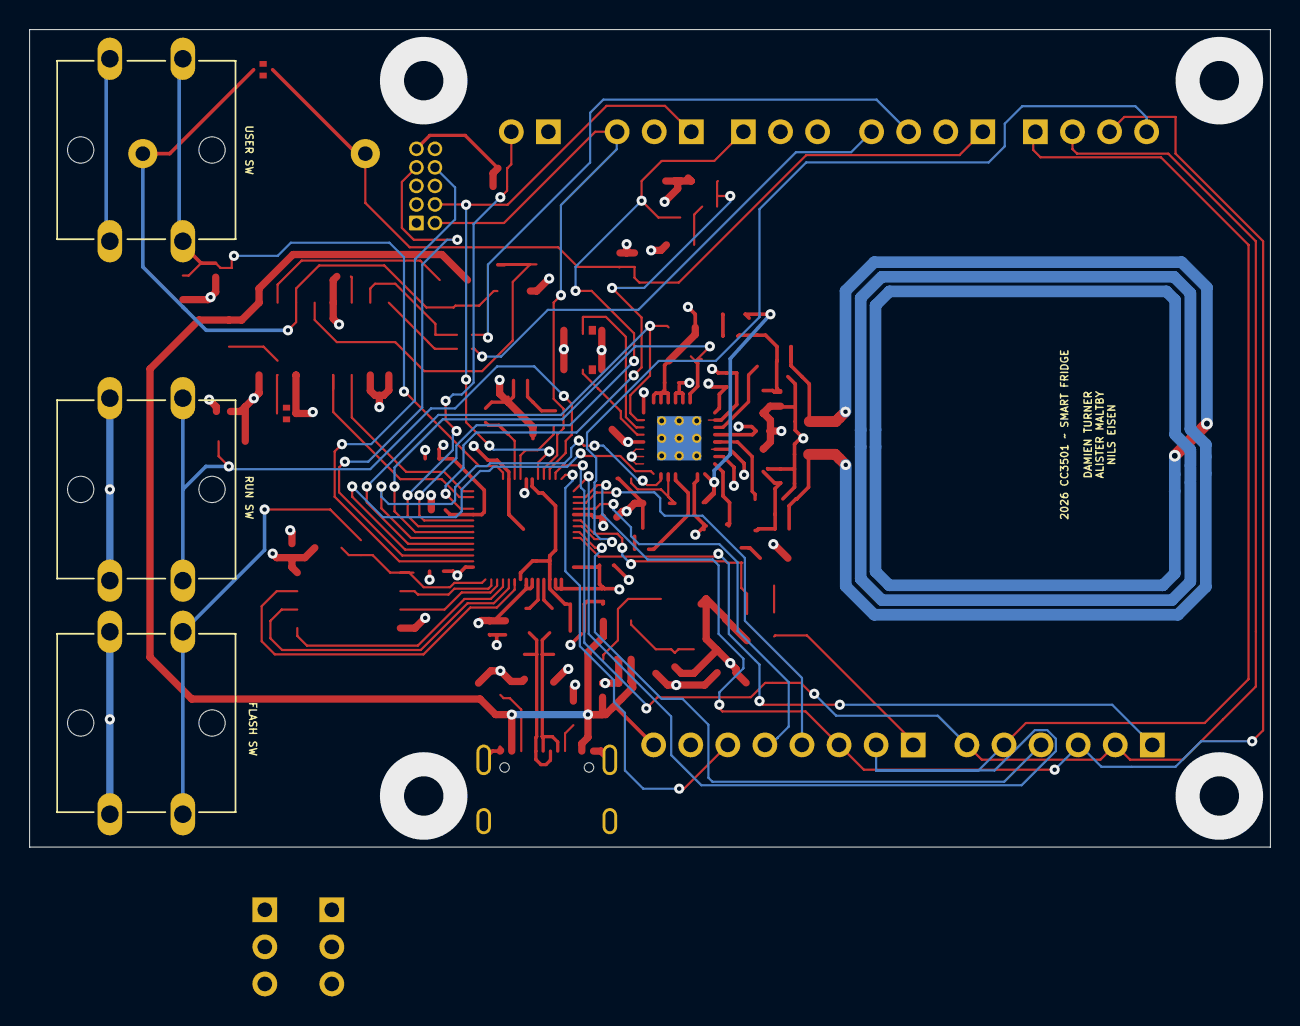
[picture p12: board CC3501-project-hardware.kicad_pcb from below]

Board: 4 copper layers, 85.0 x 56.0 mm, 118 parts (8 on the bottom side), 80 nets.

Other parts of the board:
U4: SY8089A1AAC; SOT95P285X130-5N

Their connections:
+5V: U4.1 (EN), U4.4 (IN); also elsewhere on the board
GND: U4.2 (GND); also elsewhere on the board

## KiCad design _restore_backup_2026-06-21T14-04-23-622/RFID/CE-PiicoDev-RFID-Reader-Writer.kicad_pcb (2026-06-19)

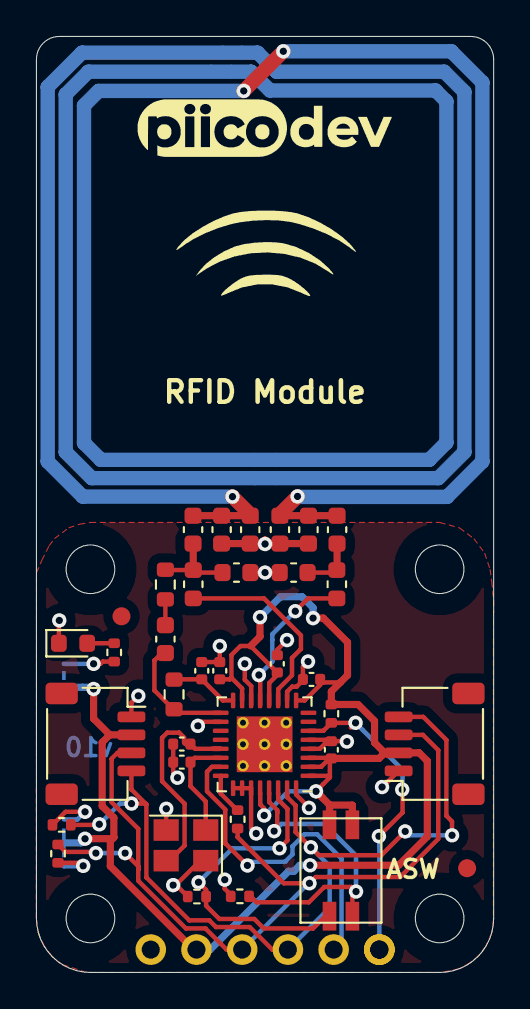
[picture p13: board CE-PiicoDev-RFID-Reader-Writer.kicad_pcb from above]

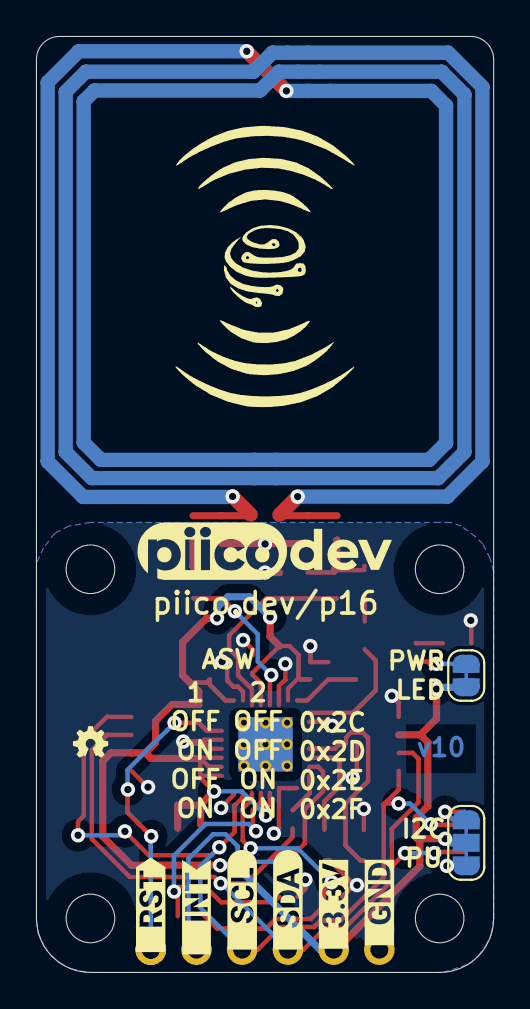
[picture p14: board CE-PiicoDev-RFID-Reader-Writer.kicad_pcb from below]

Board: 2 copper layers, 25.4 x 52.0 mm, 59 parts (16 on the bottom side), 28 nets.

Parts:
C1, C4: 22p NP0; C_0402_1005Metric
C2: 1n NP0 10%; C_0603_1608Metric
C3: 100n X7R 10%; C_0402_1005Metric
C5, C6: 62p NP0 2%; C_0603_1608Metric
C7, C8: 56p; C_0603_1608Metric
C9, C10, C15, C16: 270p NP0 2%; C_0603_1608Metric
C11, C12, C13, C14: 100n; C_0402_1005Metric
D1: LED; LED_0603_1608Metric
FID1, FID2: Fiducial; Fiducial_1mm_Mask2mm_No_Courtyard
G1: LOGO_PiicoDev; piicodev_logo_14.2x3.4mm
G3: LOGO_made-with-love; piicodev_logo_14.2x3.4mm
G6: Label_PCB_Art; Art_1
G7: Label_PCB_Art; Art_2
H1, H2, H3, H4: MountingHole; MountingHole_2.7mm_M2.5_PadClearance_1.2
J1, J2: JST_SH_SM04B-SRSS-TB_1x04-1MP_P1.00mm_Horizontal
J3: Conn_01x06_Male; PiicoDev_header_6pin
J4: Conn_01x01_Male; PiicoDev_header_1pin
JP1: LED; SolderJumper-2_P1.3mm_Bridged_RoundedPad1.0x1.5mm
JP2: I2C PU; SolderJumper-3_P1.3mm_Closed_RoundedPad1.0x1.5mm_NumberLabe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
L1, L2: 1uH; L_0603_1608Metric
LOGO1: Logo_Open_Hardware_Small; oshw
NT4, NT10, NT11: Net-Tie_2; NetTie-2_SMD_Pad0.80mm
NT8, NT9: Net-Tie_2_Top; NetTie-2_SMD_Pad0.80mm
R1, R2, R3, R6, R7, R9: 10k; R_0402_1005Metric
R4: 820R; R_0603_1608Metric
R5: 1k; R_0603_1608Metric
R11: 120R; R_0402_1005Metric
SW1: SW_DIP_x02; SW_DIP_x02_Slide_CHS-02A1
U1: MFRC522; VQFN-32-1EP_5x5mm_P0.5mm_EP3.1x3.1mm_ThermalVias
Y1: 27.12MHz 12pF; Crystal_SMD_TXC_7M-4Pin_3.2x2.5mm
kibuzzard-61B8280C, kibuzzard-61B8283F, kibuzzard-61B82819, kibuzzard-61B82827, kibuzzard-61B82831, kibuzzard-61B82849: G***; label

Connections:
+3V3: C11.1, C12.1, C13.1, C14.1, J1.2, J2.2, J3.2, JP1.1, JP2.2, R9.1, SW1.3, SW1.4, U1.1, U1.2, U1.3, U1.9, U1.12, U1.15, U1.28
/INT: J3.5, U1.23
/SCL: J1.4, J2.4, J3.4, R2.2, U1.31
/SDA: J1.3, J2.3, J3.3, R3.2, R11.2
/TURN1A: C7.1, C9.1, C15.1, NT8.1
/TURN4B: NT4.1, NT8.2
/TURN5A: NT4.2, NT9.1
/TURN5B: NT9.2, NT10.1
/TURN6A: NT10.2, NT11.1
/TURN6B: C8.1, C10.2, C16.2, NT11.2
/~RST: J3.6, J4.1, R9.2, U1.6
GND: C1.2, C3.1, C4.2, C5.2, C6.2, C9.2, C10.1, C11.2, C12.2, C13.2, C14.2, C15.2, C16.1, D1.1, J1.1, J2.1, J3.1, R6.2, R7.2, U1.4, U1.5, U1.10, U1.14, U1.18, U1.25, U1.26, U1.27, U1.32, Y1.2, Y1.4
unnamed: C1.1, U1.21, Y1.3
unnamed: C2.1, R5.1
unnamed: C2.2, R4.1, U1.17
unnamed: C3.2, R4.2, U1.16
unnamed: C4.1, U1.22, Y1.1
unnamed: C5.1, C7.2, L1.2, R5.2
unnamed: C6.1, C8.2, L2.2
unnamed: D1.2, R1.2
unnamed: JP1.2, R1.1
unnamed: JP2.1, R3.1
unnamed: JP2.3, R2.1
unnamed: L1.1, U1.11
unnamed: L2.1, U1.13
unnamed: R6.1, SW1.2, U1.29
unnamed: R7.1, SW1.1, U1.30
unnamed: R11.1, U1.24

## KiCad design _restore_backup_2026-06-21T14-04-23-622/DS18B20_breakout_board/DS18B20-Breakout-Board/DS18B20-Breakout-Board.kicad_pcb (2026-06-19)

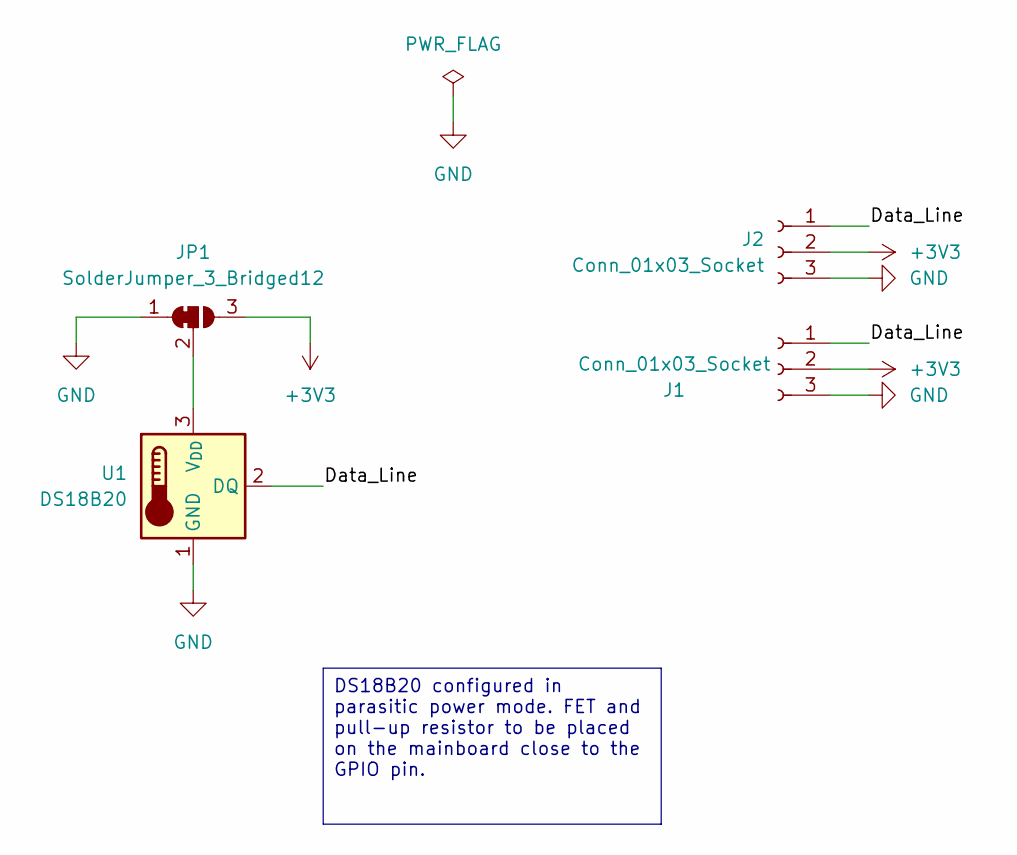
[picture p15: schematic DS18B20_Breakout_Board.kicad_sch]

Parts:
J1, J2: Conn_01x03_Socket; PinSocket_1x03_P2.54mm_Vertical
JP1: SolderJumper_3_Bridged12; SolderJumper-3_P1.3mm_Bridged12_RoundedPad1.0x1.5mm_NumberL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
U1: DS18B20; TO-92_Inline

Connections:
+3V3: J1.2, J2.2, JP1.3 (B)
/Data_Line: J1.1, J2.1, U1.2 (DQ)
GND: J1.3, J2.3, JP1.1 (A), U1.1 (GND)
unnamed: JP1.2 (C), U1.3 (V_{DD})

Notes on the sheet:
DS18B20 configured in parasitic power mode. FET and pull-up resistor to be placed on the mainboard close to the GPIO pin.

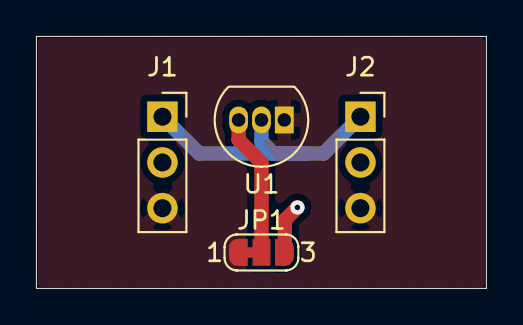
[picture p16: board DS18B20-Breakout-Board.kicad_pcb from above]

Board: 2 copper layers, 25.0 x 14.0 mm, 4 parts (0 on the bottom side), 4 nets.

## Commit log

2026-06-09 Add RP2040 and DS18B20
    [CC3501-project-hardware.kicad_sch]
2026-06-09 Wire up temp sensor wrong.
    [CC3501-project-hardware.kicad_sch]
2026-06-09 Undo wrong wiring.
    [CC3501-project-hardware.kicad_sch]
2026-06-09 Internal KiCAD test edits.
    [CC3501-project-hardware.kicad_sch]
2026-06-09 Make a wiring change.
    [CC3501-project-hardware.kicad_sch]
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2026-06-13 Add USB C and make connections to ground.
    [CC3501-project-hardware.kicad_sch]
2026-06-13 Add voltage regulator to USB input.
    [CC3501-project-hardware.kicad_sch]
2026-06-14 Add connection from USB DN/DP pins to RP2040 and include series 27R resisotor.
    [CC3501-project-hardware.kicad_sch]
2026-06-14 Added LCD, Load Cell Amplifier and Temp Sensors to schematic and made connections to RP2040.
    [CC3501-project-hardware.kicad_sch]
2026-06-15 Add JLC part number to HX711
    [CC3501-project-hardware.kicad_sch]
2026-06-15 Add annotations for future considerations.
    [CC3501-project-hardware.kicad_sch]
2026-06-15 Added lcsc lib and changed gitignore
    [CC3501-project-hardware.kicad_sch]
2026-06-15 Flash added to sch
    [CC3501-project-hardware.kicad_sch]
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2026-06-16 Revert "Merge branch 'master' of https://github.com/enolf/CC3501-project-hardware"
    This reverts commit 2500d5ad2e3feed9fc5dfb9bd824a4702660caf9, reversing
    changes made to 56ed78568c6556d2d0023d84cb985b4cc09a45fd.
    [CC3501-project-hardware.kicad_pcb, CC3501-project-hardware.kicad_sch]
2026-06-16 Reapply "Merge branch 'master' of https://github.com/enolf/CC3501-project-hardware"
    This reverts commit 1f4ff7fa30b99a2d4c13749025865a9144c5015b.
    [CC3501-project-hardware.kicad_pcb, CC3501-project-hardware.kicad_sch]
2026-06-16 Create schematic and PCB for DS18B20 breakout board
    [DS18B20 Breakout Board.kicad_pcb, DS18B20 Breakout Board.kicad_sch]
2026-06-16 Add 3D model file, fixed pathing, checked final PCB model and generated fab files.
    [DS18B20 Breakout Board.kicad_pcb, DS18B20 Breakout Board.kicad_sch, JST - XH - Thru (R) - 2Pin - 2.54mm.stp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]
2026-06-16 add design note about FET and pull-up resistor, based on peer-review feedback.
    [DS18B20 Breakout Board.kicad_sch]
2026-06-16 Added a seperate page for rp2040 required parts
    [CC3501-project-hardware.kicad_sch, untitled.kicad_sch]
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2026-06-17 Move DS18B20 breakout board into schematic.
    [CC3501-project-hardware.kicad_sch, DS18B20-Breakout-Board.kicad_pcb, DS18B20_Breakout_Board.kicad_sch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]
2026-06-17 Remove previous DS18B20 file.
    [DS18B20_Breakout_Board.kicad_sch]
2026-06-17 add new dc-dc converter with recommended circuit layout for 3.3v
    [CC3501-project-hardware.kicad_sch, rp2040components.kicad_sch]
2026-06-17 finalise dc-dc step down.
    [CC3501-project-hardware.kicad_sch]
2026-06-17 Add JLC part numbers, button and correct oscillator to Page 2
    [rp2040components.kicad_sch]
2026-06-17 add temp sensor pull up fet and pull up resistor
    [CC3501-project-hardware.kicad_sch, rp2040components.kicad_sch]
2026-06-17 add a whole bunch off stuff
    - separated TFT display and HX711 into separate pages
    - add ESD protection resistor to temp sensor
    - corrected/added various JLC PCB part numbers
    - swapped oscillator for the one used in part 1
    - moved blocks of schematic around and into other pages to neaten it all up
    - added file with download footprints, symbols, and 3D models
    - add decoupling caps for RP2040
    [CC3501-project-hardware.kicad_sch, DS18B20_breakout_board.kicad_sch, load_cell.kicad_sch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]
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2026-06-18 added most circuit to HX711 sch
    [load_cell.kicad_sch]
2026-06-18 reconfigure DS18B20 breakout board
    - Change JST from 2-pin to 3-pin
    - Add a solder jumper for switching between parasitic and external power
    [DS18B20 Breakout Board.kicad_pcb, DS18B20 Breakout Board.kicad_sch, JST - XH - Thru (R) - 3Pin - 2.54mm.stp]
2026-06-18 Breakout Board, ESD protection and TFT display updates
    [CC3501-project-hardware.kicad_sch, DS18B20-Breakout-Board.kicad_pcb, DS18B20_Breakout_Board.kicad_sch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]
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2026-06-19 Import RFID module from Core Electronics
    [CE-PiicoDev-RFID-Reader-Writer.kicad_pcb, CE-PiicoDev-RFID-Reader-Writer.sch]
2026-06-19 Link RFID Module to board.
    [.kicad_sch, CE-PiicoDev-RFID-Reader-Writer.kicad_sch]
2026-06-19 Clean up RFID module.
    [CC3501-project-hardware.csv, CC3501-project-hardware.kicad_sch, CE-PiicoDev-RFID-Reader-Writer.kicad_sch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]
2026-06-19 Removed wrong part numbers field.
    [CC3501-project-hardware.csv, CC3501-project-hardware.kicad_sch, CE-PiicoDev-RFID-Reader-Writer.kicad_sch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]
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2026-06-19 Attached part number to components.
    [CC3501-project-hardware.kicad_sch, CE-PiicoDev-RFID-Reader-Writer.kicad_sch, DS18B20_Breakout_Board.kicad_sch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]
2026-06-19 Add footprint to xtal oscillator.
    [CE-PiicoDev-RFID-Reader-Writer.kicad_sch]
2026-06-20 Fix ERC errors.
    [CC3501-project-hardware.kicad_sch, CE-PiicoDev-RFID-Reader-Writer.kicad_sch, DS18B20_Breakout_Board.kicad_sch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]
2026-06-20 Remove duplicated power flag.
    [CC3501-project-hardware.kicad_sch, DS18B20_Breakout_Board.kicad_sch, load_cell.kicad_sch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]
2026-06-20 Change wiring on temp sensor.
    [CC3501-project-hardware.kicad_sch, DS18B20_Breakout_Board.kicad_sch]
2026-06-20 Rewire TFT display to power with 5V and allowing backlight switching via FET.
    [CC3501-project-hardware.kicad_sch, DS18B20_Breakout_Board.kicad_sch, load_cell.kicad_sch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]
2026-06-20 update passive power FET from N-CH to P-CH as recommended from peer review.
    [CC3501-project-hardware.kicad_sch, rp2040components.kicad_sch]
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2026-06-20 edit HX711 configuration to match datasheet and sparkfun example as well as add JLC part numbers and display them on schematic
    [CC3501-project-hardware.kicad_sch, load_cell.kicad_sch, rp2040components.kicad_sch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]
2026-06-21 Add part numbers for USB C and RFID xtal.
    [CC3501-project-hardware.kicad_sch, CE-PiicoDev-RFID-Reader-Writer.kicad_sch, DS18B20_Breakout_Board.kicad_sch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]
2026-06-21 Add reset switch to RUN pin.
    [CC3501-project-hardware.kicad_sch, load_cell.kicad_sch, rp2040components.kicad_sch]
2026-06-21 Revert to autosave.
    [.kicad_sch, CC3501-project-hardware.kicad_sch, CE-PiicoDev-RFID-Reader-Writer.kicad_pcb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]
2026-06-21 Add symbol/footprint library linkages.
    [CC3501-project-hardware.kicad_sch, CE-PiicoDev-RFID-Reader-Writer.kicad_sch, rp2040components.kicad_sch]
2026-06-21 Add PCB with JLC config from assignment 1 pt 1.
    [CC3501-project-hardware.kicad_pcb]
2026-06-21 Add layout drawings for PCB.
    [CC3501-project-hardware.kicad_pcb]
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2026-06-21 swapped around TFT pinout to match physical board
    [tft_display.kicad_sch]
2026-06-21 add 100ohm current limit resistor to TFT LED GPIO control pin
    [tft_display.kicad_sch]
2026-06-21 add door limit switch connector and hardware debounce.
    [CC3501-project-hardware.kicad_sch, rp2040components.kicad_sch]
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2026-06-22 swapped voltage rep for potential alternative
    [CC3501-project-hardware.kicad_sch, rp2040components.kicad_sch]
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2026-06-24 finished C43 and C44 and poured with b
    [CC3501-project-hardware.kicad_pcb]
2026-06-24 Fixed 3v3 gnd cap near RFID
    [CC3501-project-hardware.kicad_pcb]
2026-08-08 Add 3D design files of the 3D printed enclosure used for demonstration
    [Money Box.step]

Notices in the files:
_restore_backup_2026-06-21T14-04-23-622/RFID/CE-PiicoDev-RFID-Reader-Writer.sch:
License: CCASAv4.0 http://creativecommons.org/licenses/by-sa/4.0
